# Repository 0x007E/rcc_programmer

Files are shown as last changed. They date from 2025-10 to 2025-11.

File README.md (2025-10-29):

   

# `RCC_programmer` - RCC (UPDI) Programmer



The `RCC_programmer` project is based on a pcb with an [FT230XS](#additional-information) to program the [RCC](https://github.com/0x0007e/rcc) (RGB LED Color Cube). It either can be programmed with the developed module or with a simple self-made [UPDI](#additional-information) converter. The deliverd software writes the defined settings with `avr-dude` over `serialupdi` onto the [ATTiny402](#additional-information).

| Experience | Level |
|:---|:-----:|
| Soldering | ?% |
| Mechanical  | ?% |
| Software | ?% |

# Downloads

| Type | File | Description |
|:---:|:---:|:---|
| Schematic | [pdf](https://github.com/0x007E/rcc_programmer/releases/latest/download/schematic.pdf) / [cadlab](https://cadlab.io/project/29709/main/files) | Schematic files |
| Board | [pdf](https://github.com/0x007E/rcc_programmer/releases/latest/download/pcb.pdf) / [cadlab](https://cadlab.io/project/29709/main/files) | Board file |
| Drill | [pdf](https://github.com/0x007E/rcc_programmer/releases/latest/download/drill.pdf) | Drill file |
| PCB | [zip](https://github.com/0x007E/rcc_programmer/releases/latest/download/kicad.zip) / [tar](https://github.com/0x007E/rcc_programmer/releases/latest/download/kicad.tar.gz) | KiCAD/Gerber/BoM/Drill files |
| Mechanical | [zip](https://github.com/0x007E/rcc_programmer/releases/latest/download/freecad.zip) / [tar](https://github.com/0x007E/rcc_programmer/releases/latest/download/freecad.tar.gz) | FreeCAD/Housing and PCB (STEP) files |
| Installer | [exe](https://0x007e.github.io/rcc_programmer/clickonce/setup.exe) | ClickOnce installer (x64) for RCC Programming software |
| Portable | [zip](https://github.com/0x007E/rcc_programmer/releases/latest/download/programmer.zip) / [tar](https://github.com/0x007E/rcc_programmer/releases/latest/download/programmer.tar.gz) | Software (x64) for Programming the RCC |

# Hardware

There are two parts of the hardware. The pcb and the housing of the `RCC_programmer`. The pcb is created with [KiCAD](#additional-information) and the housing with [FreeCAD](#additional-information) . The software is programmed with [Visual Studio](#additional-information). All files are built with `github actions` so that they are ready for a production environment. The housing is printed with a 3D-printer (`Dremel 3D40`) and the software is build as ClickOnce application that can be installed over a simple setup file and keeps automatically up-to-date.

## PCB

The circuit board is populated on one side (Top). The best way for soldering the `SMD` components is within a vapor phase soldering system.

### Top Layer

Top Layer

### Bottom Layer

Bottom Layer

## Mechanical

The housing has a tolerance of `0.2mm` on each side of the case. So the pcb should fit perfectly in the housing. The tolerance can be modified with `FreeCAD` in the `Parameter` Spreadsheet.

### Assembled

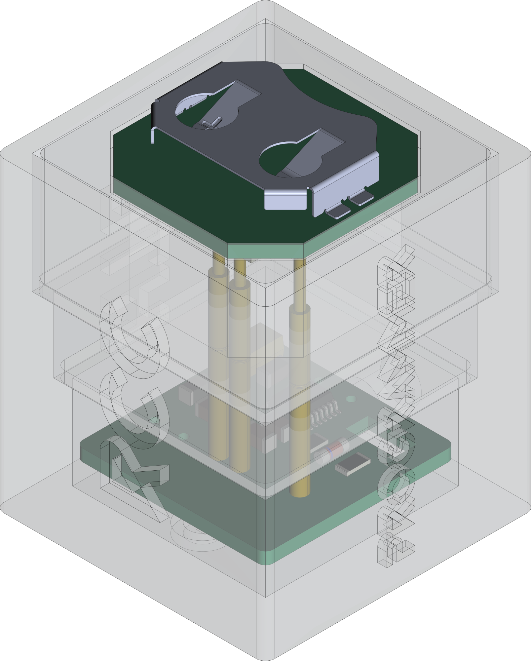
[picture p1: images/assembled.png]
Assembled


### Exploded

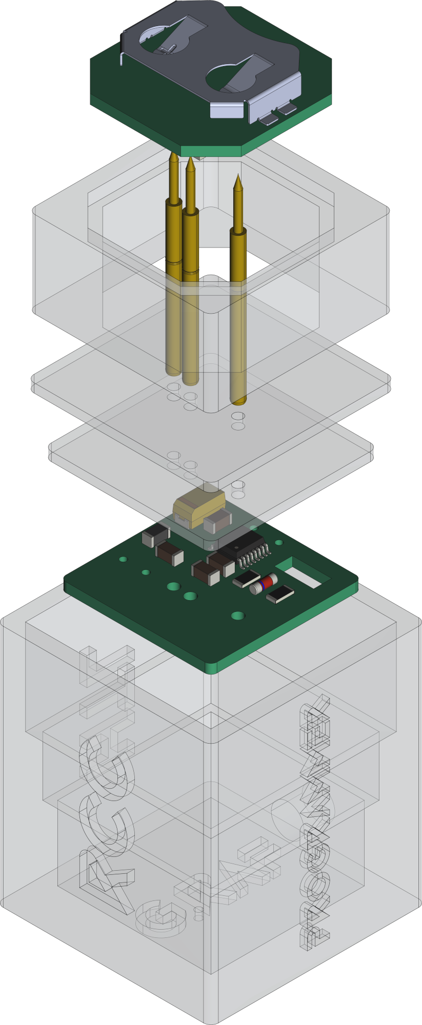
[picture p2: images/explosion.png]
Exploded


# Programming/Setup

The `RCC_programmer` is powerd over USB with `5V` and uses the internal `3V3` converter of the `FT230XS` as main programming voltage. The programming software itself uses avr-dude in background and a simple [UPDI](#additional-information) circuit to program the `RCC`. It can be programmed over [UPDI](#additional-information) on `TP1`. The firmware for the cube can be downloaded in the [download section](#downloads).

``` bash
#               RCC                     RCC_programmer (Adapter)
#                                     +-------------------------+      +---------------------+
#                                     |          TXD     U  +---+---+  |                     |
#     +---------------------+         |     U     +      S  |  USB  |--+ +-----------------+ |
#     |                     |         |     P    +++     B  +---+---+  | | RCC Programmer  | |
#     |    RCC - Color Cube |         |     D    / \     /      |      | | ~~~~~~~~        | |
#     |                  +--+--+   +--+--+  I    +++     U      |      | | ~~~~~           | |
#     |              VCC | TP3 +---+ VCC |        |      A      |      | | ~~~~~~~~~~~~    | |
#     |              GND | TP2 +---+ GND |  B    +++     R      |      | |                 | |
#     |                  +--+--+   +--+--+  R    | |     T      |      | +-----------------+ |
#     |                     |         |     I    | |            |      |                     |
#     |                  +--+--+   +--+--+  D    +++   +------+ |      | Computer            |
#     |             UPDI | TP1 +---+ PDI +--G-----+    | 3V3  | |      |                     |
#     |                  +--+--+   +--+--+  E    RXD   +------+ |      +---------------------+
#     +---------------------+         +-------------------------+
#
```

# Software

| Icon | Description |
|:---:|:---|
| Programmer Icon | ClickOnce installable |

> The app can be installed as clickonce application that automatically gets updated or run as portable app that need to be updated manually. Both files (setup/portable) are found in the [download section](#downloads).

The software loads avr-dude and the current firmware of the `RCC` from predefined repositories in `appsettings.json`. By clicking onto the LEDs the color of each LED can be defined. With the intensity trackbar the brightness of the LEDs can be adjusted. To program the `RCC` the correct selection of the serial port is necessary. By hitting the program button the `RCC` gets programmed over `serialupdi` with `avr-dude` (if the programmer is connected correctly with the `RCC`).

> IMPORTANT: The battery should not be mounted during programming. There will be a short circuit between the internal `3V3` of the `FT230XS` and the battery!!!

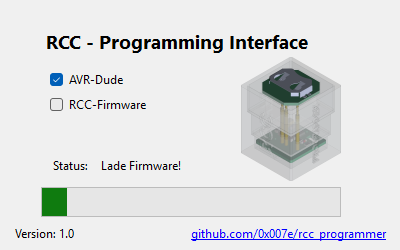
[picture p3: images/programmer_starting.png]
Programmer Starting


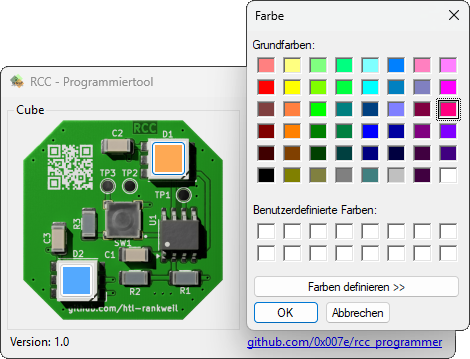
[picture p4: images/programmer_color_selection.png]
Programmer Selection


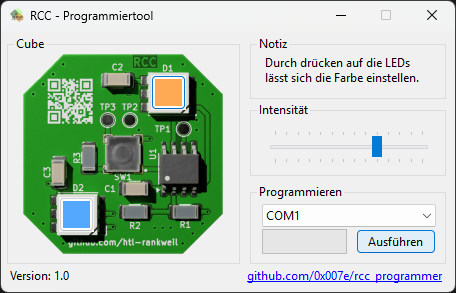
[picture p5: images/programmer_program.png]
Programmer Program


# Additional Information

| Type | Link | Description |
|:---:|:---:|:---|
| ATtiny402 | [pdf](https://ww1.microchip.com/downloads/en/DeviceDoc/ATtiny202-402-AVR-MCU-with-Core-Independent-Peripherals_and-picoPower-40001969A.pdf) | ATtiny microcontroller |
| FT230XS | [pdf](https://ftdichip.com/wp-content/uploads/2021/10/DS_FT230X.pdf) | FT230XS Datasheet |
| UPDI | [web](https://github.com/0x007e/updi) | UPDI-Adapter with AVR-Dude |
| Visual Studio | [web](https://visualstudio.microsoft.com/) | Download page for Visual Studio |
| KiCAD | [web](https://www.kicad.org/) | KiCAD project page |
| FreeCAD | [web](https://www.freecad.org/) | FreeCAD project page |

---

R. GAECHTER

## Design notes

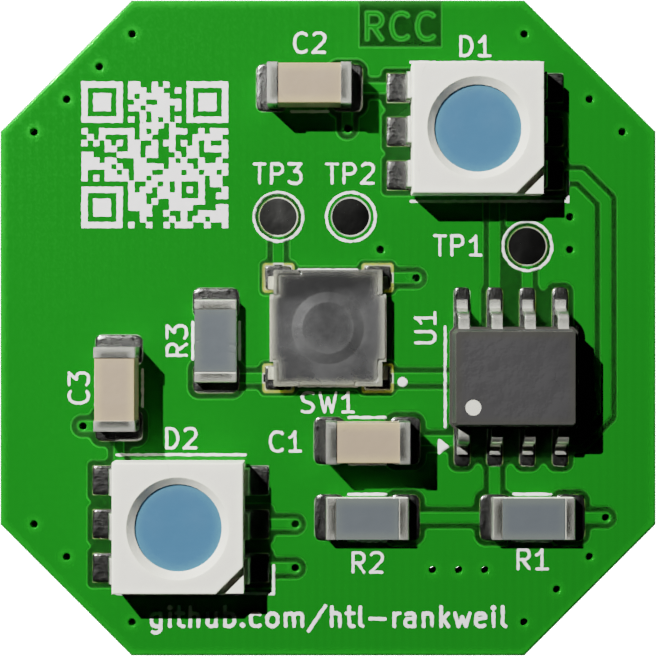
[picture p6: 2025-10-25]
Programmer/Resources/rcc.png

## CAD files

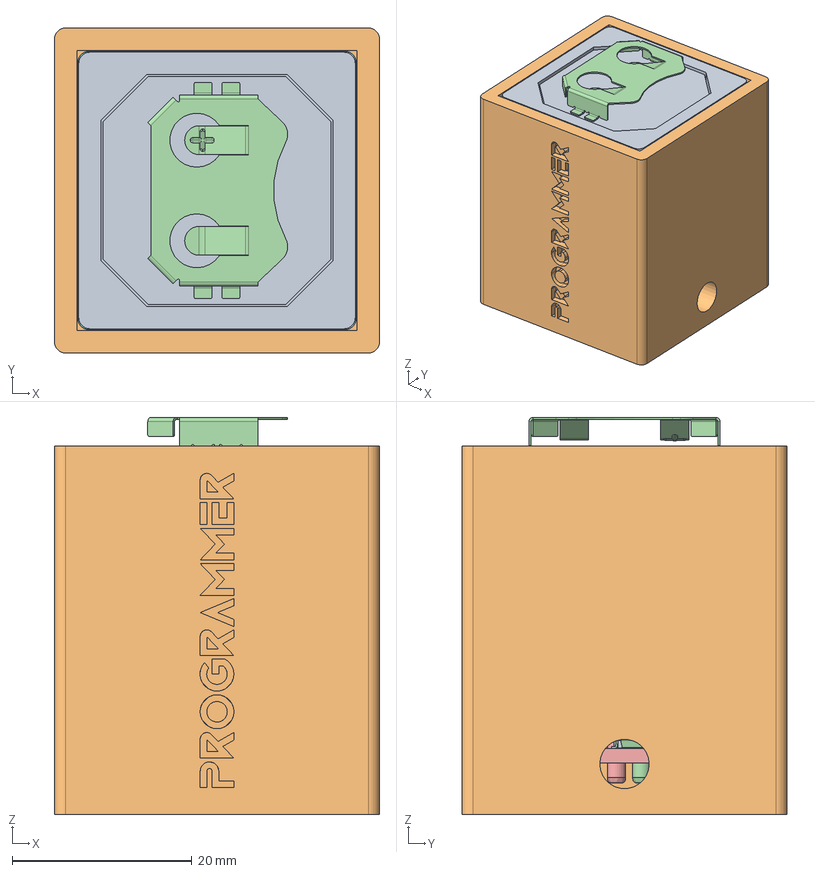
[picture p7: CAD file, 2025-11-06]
mechanical/housing.FCStd
36.2 x 36.2 x 44.2 mm
Pcb_1096
R2_R_1206_3216Metric_a244ae71ee7f
D2_LED_RGB_5050_6_3082613c1204
C2_C_1206_3216Metric_b2c0b2178a0f
C3_C_1206_3216Metric_2d6a083c182e
U1_SOIC_8_39x49mm_P127mm_ced3e6da737e
SW1_1_b49bc00616b6
R3_R_1206_3216Metric_352e77470e97
C1_C_1206_3216Metric_55e30c71a8e1
R1_R_1206_3216Metric_4fa9a57fca02
D1_LED_RGB_5050_6_e07a5316f1e2
BH-67D-5_BH-67D-5
Pcb_66df
R3_R_1206_3216Metric_43555c9aa686
C4_C_1206_3216Metric_2f6f10e902b8
C5_C_1206_3216Metric_366ead803c8f
C3_C_1206_3216Metric_b89ce79745f8
C1_CP_EIA_6032_28_Kemet_C_96bc27721f29
D1_D_MiniMELF_Standard_884efb1337ad
U1_SSOP-16_3.9x4.9mm_P0.635mm_8487508563c1
C2_C_1206_3216Metric_6f0a74450c76
FB1_L_1206_3216Metric_750d457454b0
R4_R_1206_3216Metric_39c1efd3bc68
Acrylglass_Top
Case
Acrylglass_Bottom
Pogo_VCC
Pogo_GND
Pogo_PDI

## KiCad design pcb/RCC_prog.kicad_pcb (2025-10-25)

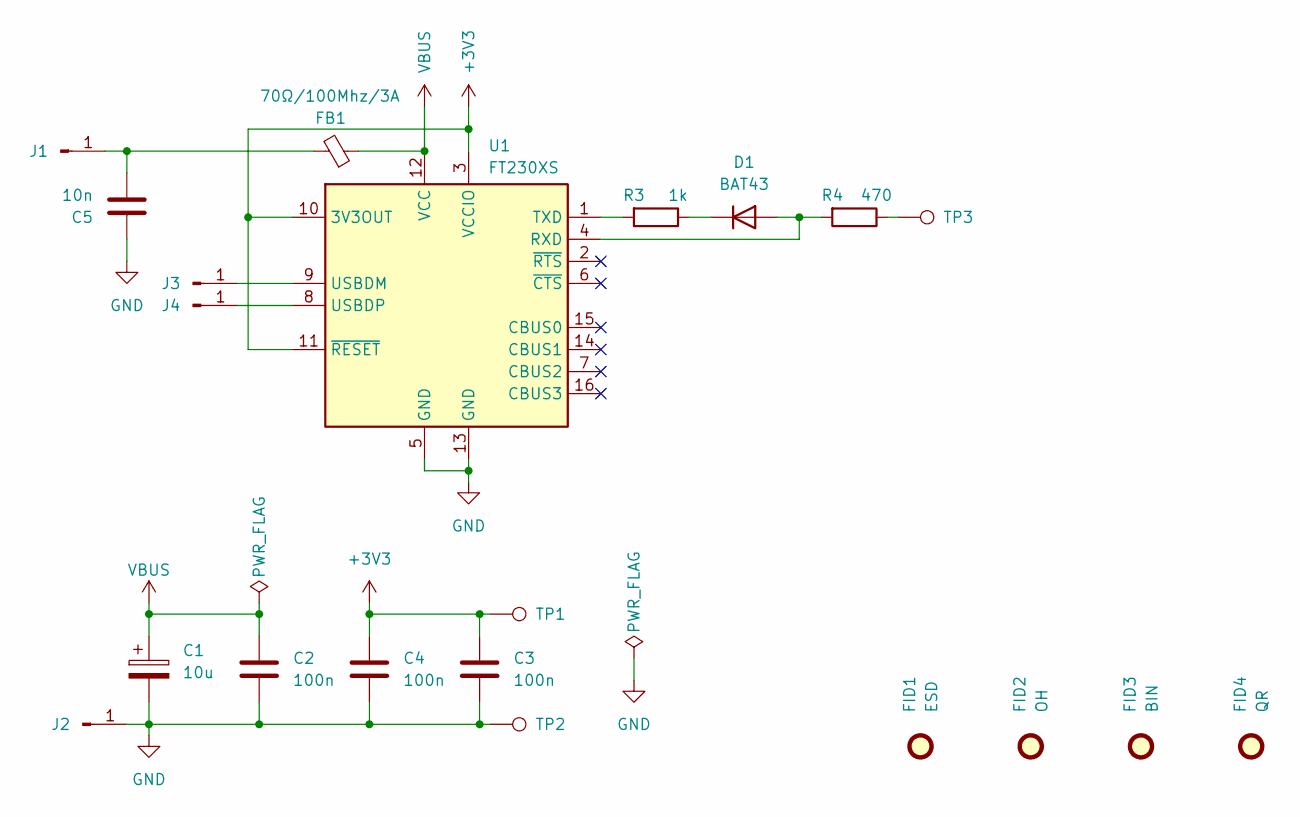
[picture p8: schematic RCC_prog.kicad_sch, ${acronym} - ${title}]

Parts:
C1: 10u; CP_EIA-6032-28_Kemet-C
C2, C3, C4: 100n; C_1206_3216Metric
C5: 10n; C_1206_3216Metric
D1: BAT43; D_MiniMELF
FB1: 70Ω/100Mhz/3A; L_1206_3216Metric
FID1: ESD; ESD-Logo_6.6x6mm_SilkScreen
FID2: OH; OSHW-Logo_5.7x6mm_SilkScreen
FID3: BIN; WEEE-Logo_4.2x6mm_SilkScreen
FID4: QR; QR_0x007e
J1, J2, J3, J4: Conn_01x01_Pin; SolderWire-0.5sqmm_1x01_D0.9mm_OD2.1mm
R3: 1k; R_1206_3216Metric
R4: 470; R_1206_3216Metric
TP1, TP2, TP3: TestPoint; Pogo_Pad_L3.2mm_B2.2mm_D1.75
U1: FT230XS; SSOP-16_3.9x4.9mm_P0.635mm

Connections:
+3V3: C3.2, C4.2, TP1.1, U1.3 (VCCIO), U1.10 (3V3OUT), U1.11 (~RESET)
GND: C1.2, C2.1, C3.1, C4.1, C5.1, J2.1, TP2.1, U1.5 (GND), U1.13 (GND)
unnamed: D1.2 (A), R4.2, U1.4 (RXD)
unnamed: D1.1 (K), R3.1
unnamed: C5.2, FB1.2, J1.1
unnamed: J3.1, U1.9 (USBDM)
unnamed: J4.1, U1.8 (USBDP)
unnamed: R4.1, TP3.1
unnamed: R3.2, U1.1 (TXD)
VBUS: C1.1, C2.2, FB1.1, U1.12 (VCC)

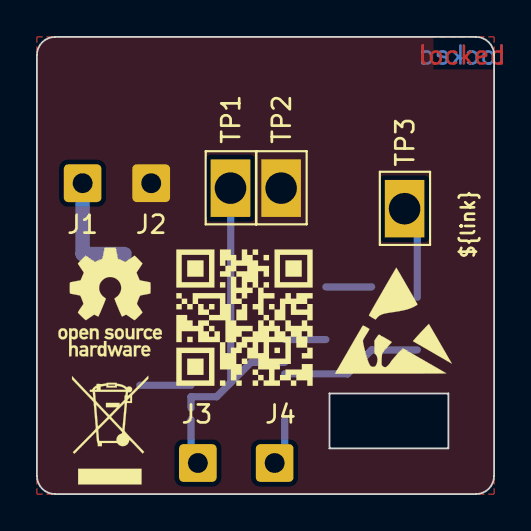
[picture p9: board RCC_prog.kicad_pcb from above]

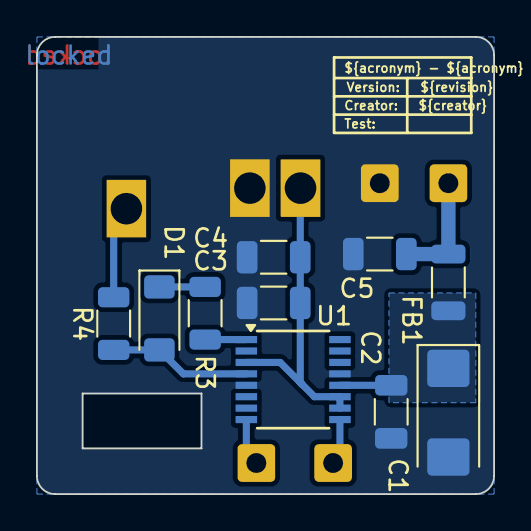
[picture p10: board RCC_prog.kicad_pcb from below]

Board: 2 copper layers, 25.4 x 25.4 mm, 21 parts (10 on the bottom side), 10 nets.

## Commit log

2025-10-26 Add housing for programmer
    [housing.FCStd]
2025-10-27 Change certificate fingerprint
2025-10-28 Remove battery from design
    [housing.FCStd]
2025-11-06 Optimize cable outlet
    [housing.FCStd]
2025-11-06 Update cable outlet

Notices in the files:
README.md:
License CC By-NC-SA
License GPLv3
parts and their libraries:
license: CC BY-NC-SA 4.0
